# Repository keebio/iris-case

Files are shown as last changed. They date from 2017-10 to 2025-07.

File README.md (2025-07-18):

Iris Keyboard Case
==================

Here are the case design files for the [Iris](https://keeb.io/products/iris-keyboard-split-ergonomic-keyboard). It's a sandwich-style case with cutouts to accommodate the USB jack and the TRRS jack.

## Iris CE / Iris LM / Iris AE / Iris SE

Iris CE parts are in this repository: https://github.com/keebio/iris-ce-case

Iris LM parts are in this repository: https://github.com/keebio/iris-lm-case

Iris AE parts are in this repository: https://github.com/keebio/iris-ae-case

Iris SE parts are in this repository: https://github.com/keebio/iris-se-case

Case pieces
-----------

The Iris sandwich case consists of these pieces:

- Switch plate (Required)
- Bottom plate (Required)
- Middle layer (Optional)
- Top rim or Top shell (Optional)

### Case/Plate Versions

Before the release of the Iris Rev. 5 PCBs, the case parts for Rev. 3 & 4 used the same parts. However, with the release of Rev. 5-8 PCBs, the screw holes needed to be relocated to accommodate the wider USB-C port used for interconnect. Therefore, new case parts needed to be made to support the newer PCBs.

The newer case parts are called [Phoenix Edition (PE)](phoenix-edition-PE/), while the older Iris parts are now called [Legacy Edition (LE)](legacy-edition-LE).

Phoenix Edition parts and Legacy Edition parts are not compatible with each other due to the different placement of screw holes.

PE parts are compatible with Rev. 3 through 8 PCBs.

LE parts are compatible with Rev. 3 & 4 PCBs.

See additional info about Legacy Edition files in its [README](legacy-edition-LE/README.md).

Iris PE (Phoenix Edition) Parts
-------------------------------
### 3D-print STL files

For the 3D-print STL files, there are two sets of files, ones for the top shell, and ones for the middle layer. For each of these sets, there are different files based on how thick your plates are. If you have the FR4 plates or Stainless steel plates, then use the files for 1.5mm plate. If you are using 3mm acrylic plates, then use the files for the 3mm plate.

For the middle layer files for 1.5mm plates, there are two sets of files: one with a lip and one without a lip. The "lip" refers to the portion of the middle layer that extends past the standoffs and covers the sides of the 1.5mm plate, to hide the edges from view. The "No Lip" version may be more desirable for you to use if you are not using a top shell.

If you are using the top shells, you will need to use longer M2 screws, as the top shell has been designed to be threaded into directly from underneath. For 1.5mm plates, you will need [18mm screws](https://keeb.io/products/m2-screws-and-standoffs), and for 3mm plates, you will need 22mm screws.

If you choose to print the ErgoDox-style tenting legs, you will need six M3 screws (at least 16mm) and six M3 nuts. The legs and washers are best printed at 0.16mm quality or better.

Additional notes
----------------

Some of the files only have a left half, just mirror the file to produce a right half if needed.

Design info
-----------

A lot of these files have been derived from the following file: [iris-plate-design.ai](references/iris-plate-design.ai). By toggling various layers in that file, you can see various info on switch cutouts, screw holes, inner/outer edges, etc.

Screws and Standoffs
--------------------

This case was designed to use M2 screws and standoffs. The holes in the middle layers are for the standoffs, while the holes in the top and bottom layers are only wide enough for the screws. M2 screws and standoffs that fit the case can be purchased at Keebio: [M2 Screws & Standoffs](https://keeb.io/products/m2-screws-and-standoffs)

Fabrication of Acrylic Parts
----------------------------

### Places to go

- [Sculpteo](https://www.sculpteo.com)
- [Ponoko](https://www.ponoko.com)

### Middle Layer Thickness
If you're having the middle layers made, from the top of the switch plate to the top of the bottom plate, the minimum distance between the two required is 12mm if the plastic on the header pins is removed. The requirement is slightly more (about 13.5mm) if you leave the plastic on. Therefore, the following middle layer thicknesses are needed based on the thickness of the switch layer:

- 1.5mm Stainless steel switch plate: 10.5mm
    - Usually accomplished with:
        - 2x4.5mm + 1x1.5mm layers
        - or 3x3mm + 1x1.5mm layers
        - or 4x3mm layers
- 3mm acrylic switch plate: 9mm
    - Usually accomplished with:
        - 2x4.5mm layers
        - or 3x3mm layers

STL Files for 3D printing
-------------------------
A couple of STL files have also been included for the middle layers and are both single pieces. They are designed for the left half, so to get the right half, you will need to flip them within your slicer software.

One version allows the Ergodox EZ legs to be used with it. In addition to the legs, you'll need M3 nuts to allow the leg screws to screw into.

Community-Made Files
--------------------
Files not designed by Keebio are placed into the [community-made](community-made/) folder and also include links to other designs not hosted in this repository.

License
-------
These case files are released under the MIT License.

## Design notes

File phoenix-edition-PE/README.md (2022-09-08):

# Iris PE Case Notes

## 1u Adapter for 3mm Plates

For the 3mm acrylic plates, due to the enlarged cutouts at the thumb area for the stabilizer, using two 1u keys there can be a bit loose sometimes. To remedy this, one thing you can do is 3D-print an [adapter for the thumb area](Iris%20PE%201u%20Adapter%20for%203mm%20Plates.stl). This adapter will also the two switches to clip in and stay in place better.

Once printed, insert the adapter from the underside of the plate, as shown here:

Bottom view:
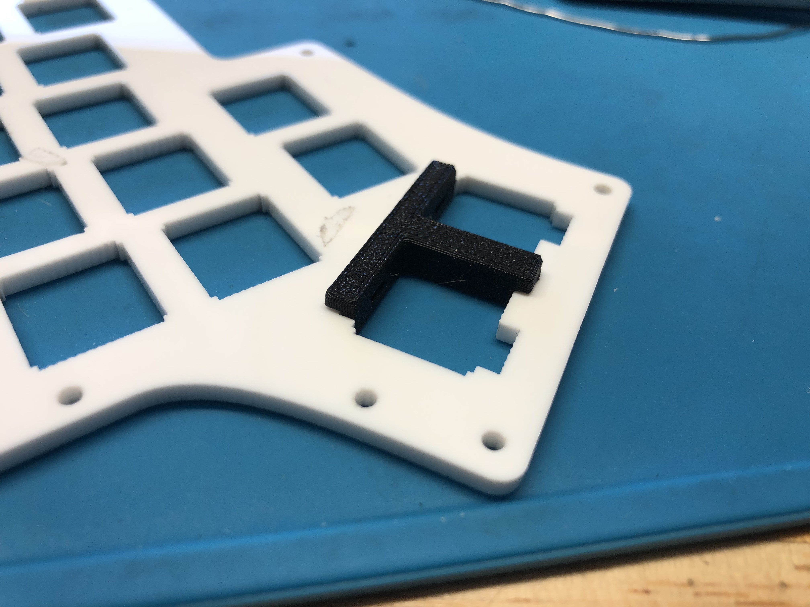
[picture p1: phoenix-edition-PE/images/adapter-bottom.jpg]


Top view:
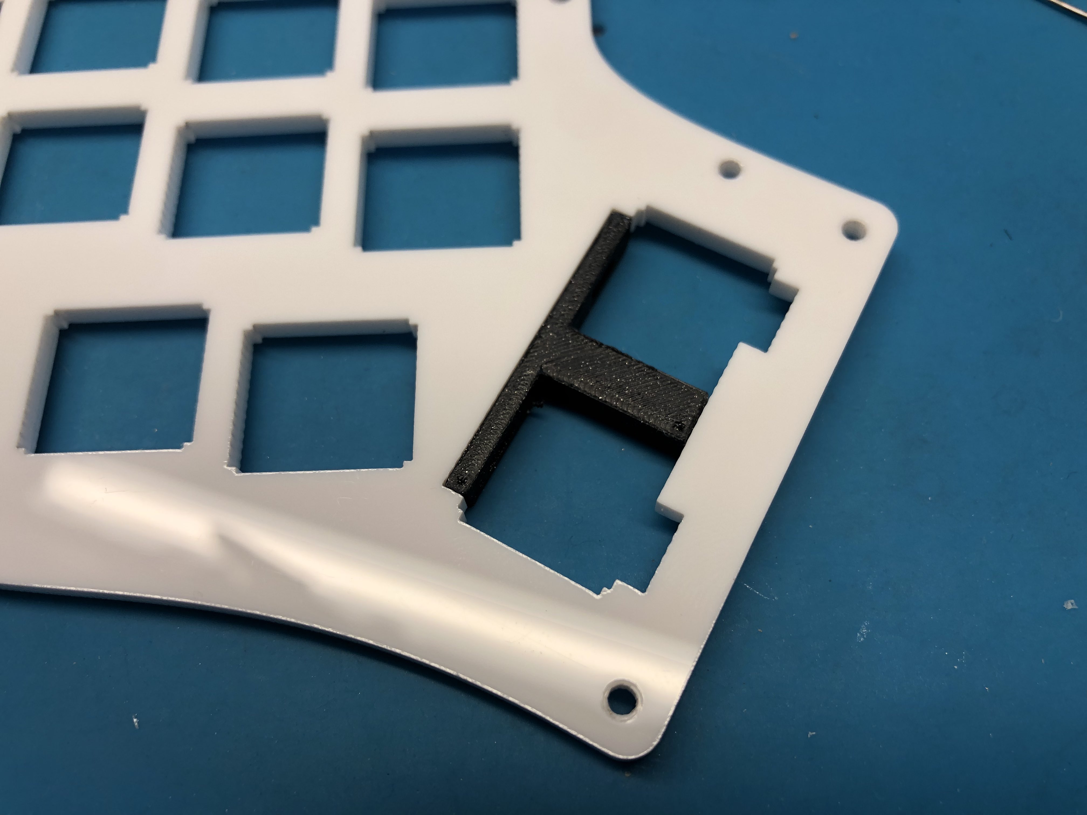
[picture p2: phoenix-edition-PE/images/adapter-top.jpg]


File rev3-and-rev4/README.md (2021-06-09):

Iris Rev. 3 & 4 Files
=====================

Iris Rev. 3 and 4 PCBs have the same exact USB-C and TRRS port positioning, so they also use the same case design.

Most of the files are designed for the the left half, so to get the right half, just mirror the file

Top Shell Files
---------------

For the top shell files in this folder, the screws are threaded in from underneath, instead of from the top for the files in the top level folder. The main benefit of this style is that the screws are not visible from the top.

The depth of the screw hole is about 5mm, so the length of the M2 screw you need with depend on the thickness of the plates and mid layer you use. Make sure the screw threads into the top shell for at least 3mm. For example, if you are using 1.5mm switch/bottom plates and 12mm middle layer, then you would need to use 18mm screws at the minimum (3 + 1.5 + 12 + 1.5 = 18).

Middle Layer Files
------------------

Since some of the middle layer files have port cutouts, the version that needs to be used is dependent on the the switch plate thickness. For FR4 plates, use the files designated for 1.5mm plates. For 3mm acrylic plates, use the files for 3mm plates.

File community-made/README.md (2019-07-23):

Community Made Files
====================

This folder contains files generated by other people in the community. If you have any questions about these files, please contact the creator of those files.

Projects on Thingiverse
-----------------------

- [Iris Keyboard Case (v2) vy holtenc](https://www.thingiverse.com/thing:3186129)
- [Keebio Iris v2.5+ middle layer with 3D-printed tenting legs by MichaelTV](https://www.thingiverse.com/thing:3392322)
- [Iris keyboard case by botstyle](https://www.thingiverse.com/thing:3545130)

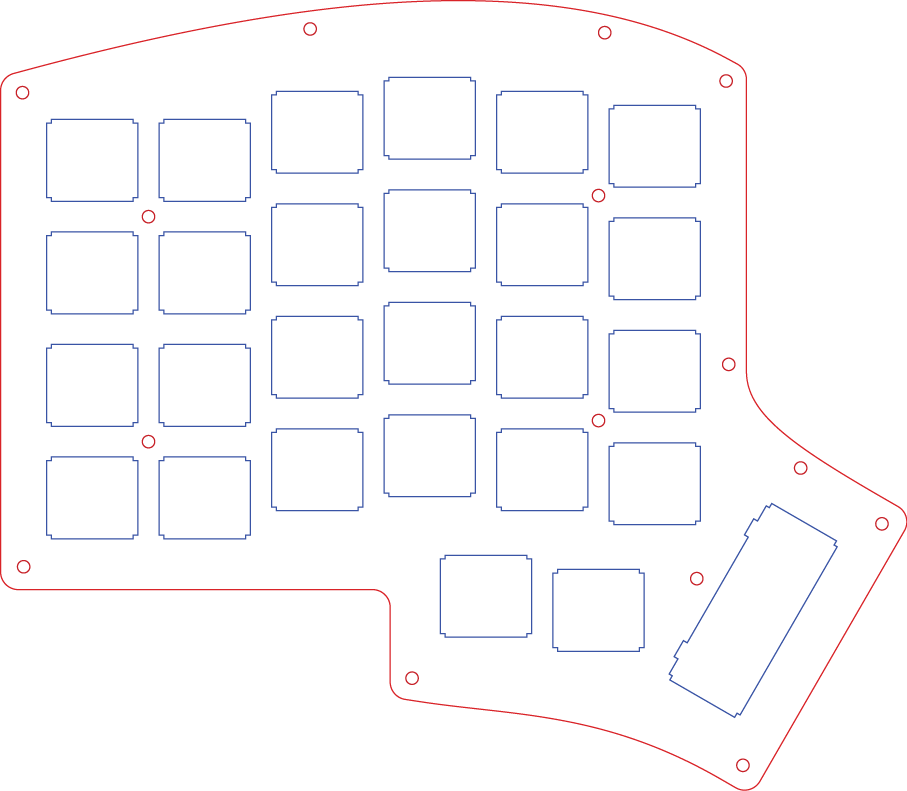
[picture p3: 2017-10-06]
images/iris-switch-plate.png

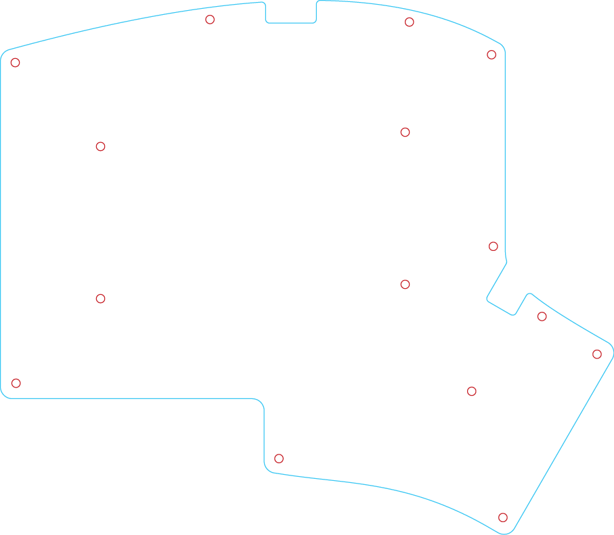
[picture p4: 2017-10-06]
images/iris-bottom-plate.png

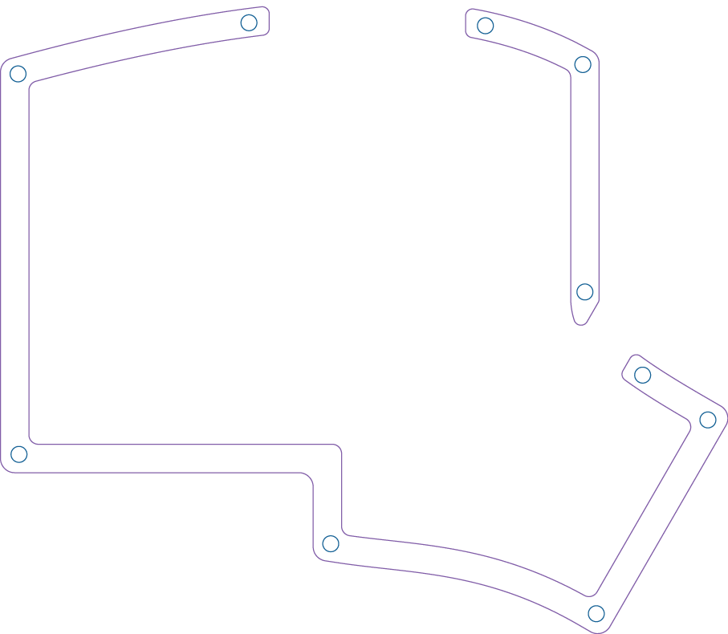
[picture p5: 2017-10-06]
images/iris-middle-layer.png

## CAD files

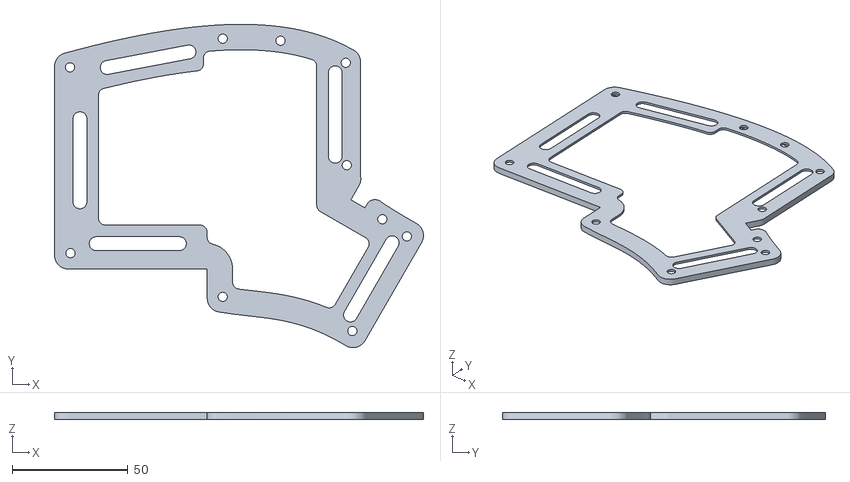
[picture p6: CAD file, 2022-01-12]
Iris Bottom Plate SKUF Alignment Guide.stl
159.4 x 139.7 x 3.00

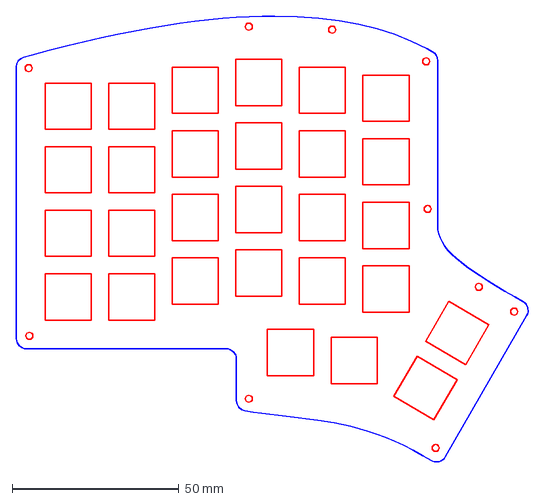
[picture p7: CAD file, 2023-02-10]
phoenix-edition-PE/iris-PE-switch-plate-mx-1u-only.dxf
153.9 x 133.7 mm

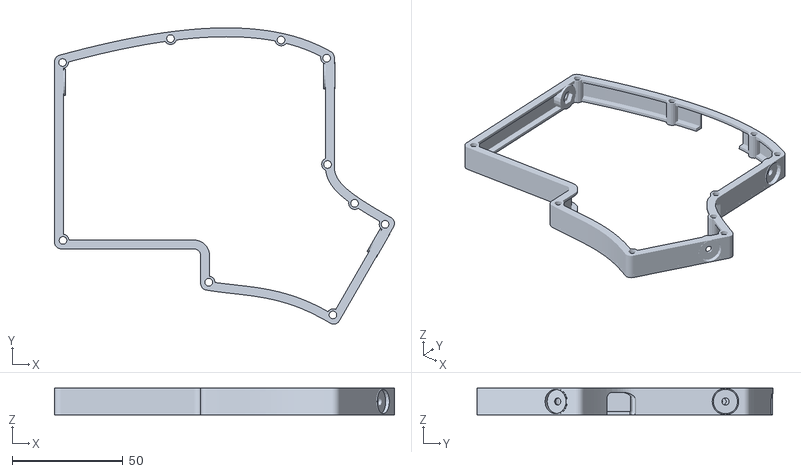
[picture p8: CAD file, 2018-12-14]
rev2-only/Iris R2 Thin Shell Tenting.stl
153.4 x 133.7 x 12.0

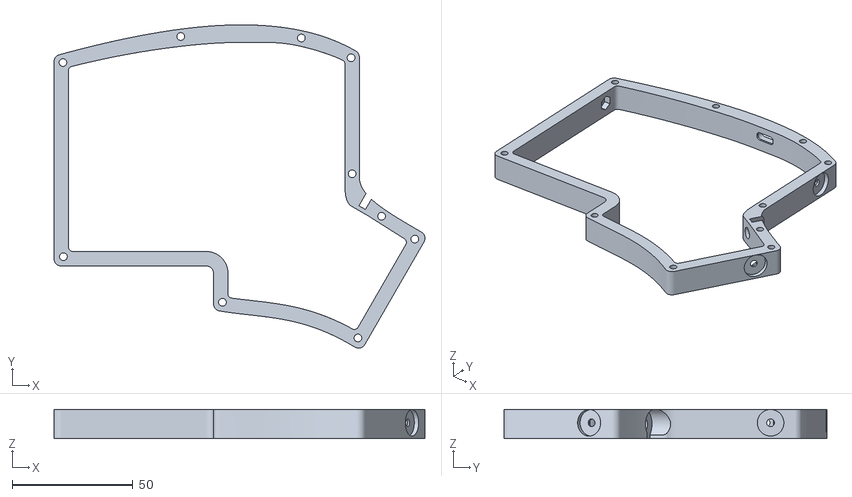
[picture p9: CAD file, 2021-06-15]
rev3-and-rev4/Iris R4 Middle Layer - Ergodox Tent Kit for 3mm Plate.stl
153.4 x 133.7 x 12.0

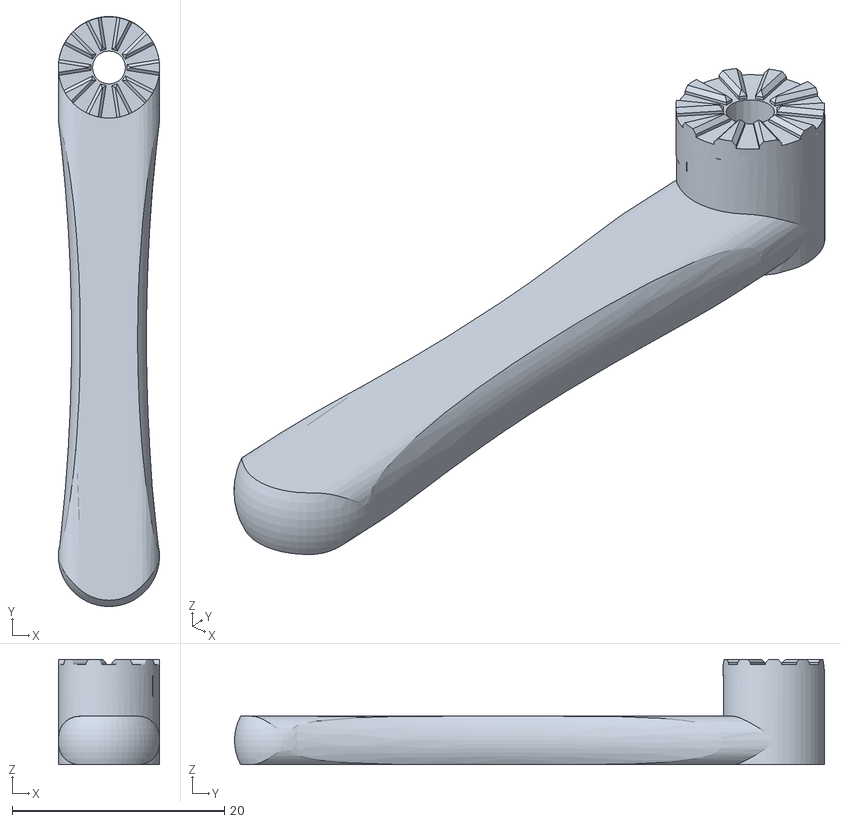
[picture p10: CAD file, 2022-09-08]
tenting-kit/ErgoDox-style Toothed Tenting Leg.stl
9.53 x 55.6 x 9.90

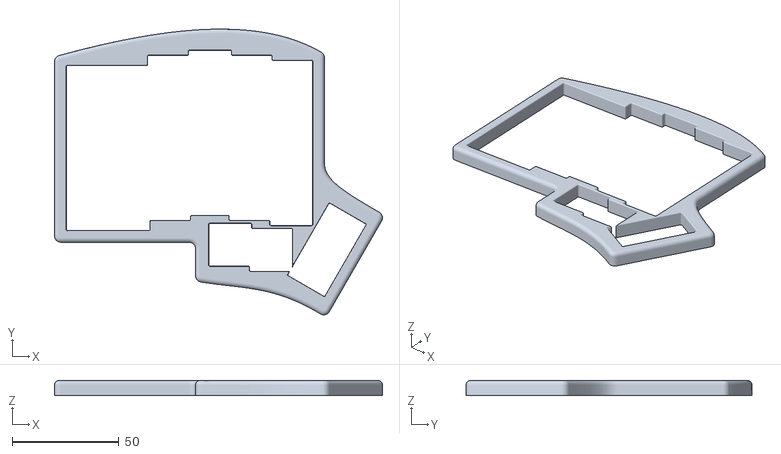
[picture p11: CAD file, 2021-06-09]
rev3-and-rev4/Iris Top Shell Rev. 4.stl
153.4 x 133.7 x 7.00

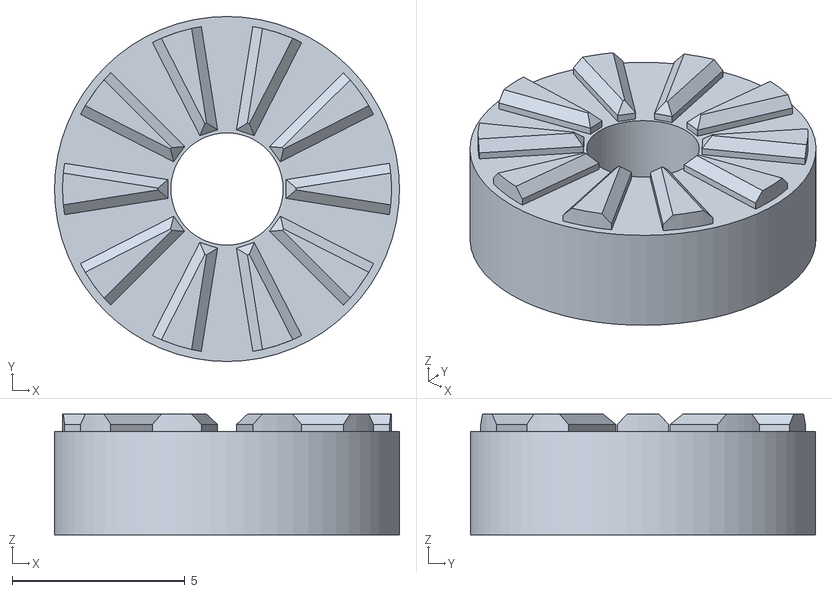
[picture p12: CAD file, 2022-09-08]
tenting-kit/ErgoDox-style Toothed Tenting Leg Adapter.stl
10.0 x 10.00 x 3.50

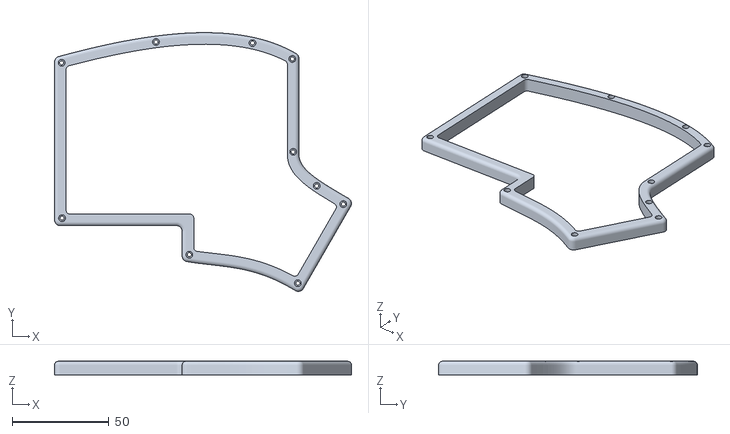
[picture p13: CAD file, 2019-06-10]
Iris Hi-Pro Top - Thin Rim.stl
153.5 x 133.7 x 7.00

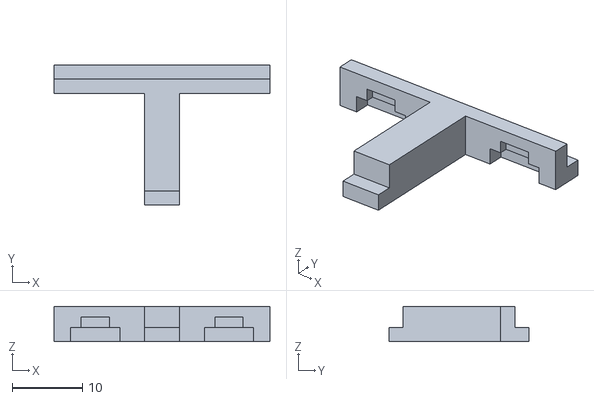
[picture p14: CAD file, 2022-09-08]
phoenix-edition-PE/Iris PE 1u Adapter for 3mm Plates.stl
30.8 x 20.0 x 5.00

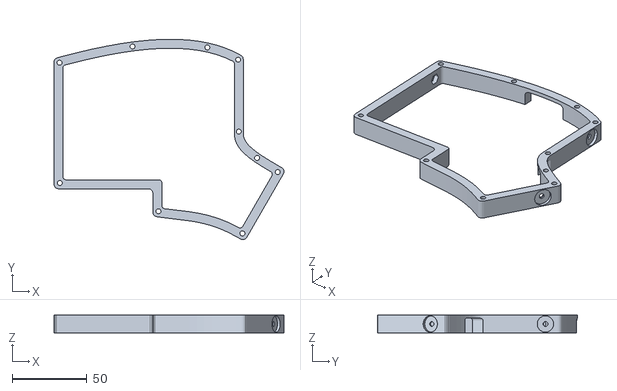
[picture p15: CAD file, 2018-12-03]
rev2-only/Iris R2 Middle Layer - Ergodox Tent Kit.stl
153.4 x 133.7 x 12.0

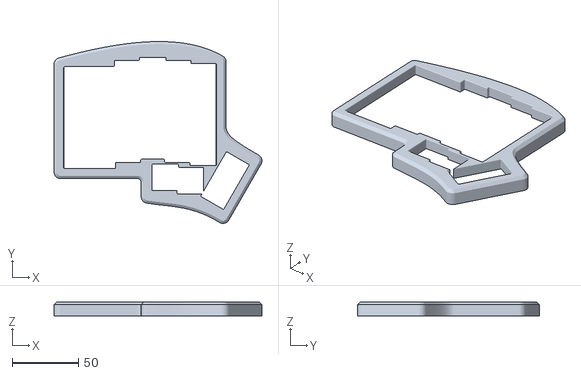
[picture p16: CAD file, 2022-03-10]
phoenix-edition-PE/Iris PE Top Shell for 3mm plate.stl
157.4 x 137.7 x 10.7

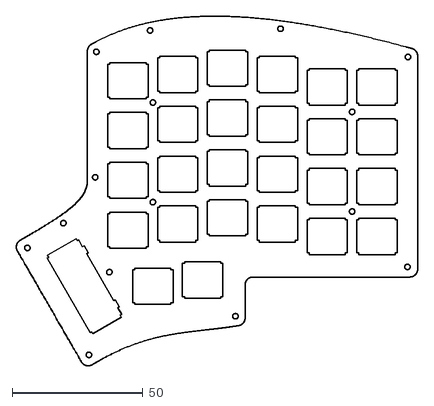
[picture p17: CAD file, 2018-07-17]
top_left.dxf
153.5 x 133.7

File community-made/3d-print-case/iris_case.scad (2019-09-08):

////////////////////////////
// User configurable options
////////////////////////////

two_unit_thumb = false;
stabilizers = true;
usb_c_pro_micro = true;
trrs_diameter = 6.55;
selector = 1;

///////////////////////////////
// Source code below this point
///////////////////////////////

$fs = .3;
$fa = 6;

mx_switch_height = 5;
pcb_height = 1.6;
trrs_jack_size = 5;
plate_thickness = 1.5;
height = mx_switch_height + pcb_height + trrs_jack_size + plate_thickness;
wall_thickness = 1.8;

_1_4th = 1/4 * 25.4;
key_distance = 3*_1_4th;
thumb_angle = -29.36;
thumb_offset = 5 * key_distance + 26.19;

_3_32nds = 3/32 * 25.4;
col3and5Shift = 2*_3_32nds;
col4Shift = 3*_3_32nds;
col6Shift = _3_32nds;

screw_head_diameter = 6.75;

mini_usb_port_width = 7.5;
usb_c_port_width = 9;

usb_port_height = usb_c_pro_micro == true ? 3.2 : 2.5;
left_usb_z_position = height - mx_switch_height - pcb_height - usb_port_height/2;
right_usb_z_position = plate_thickness + usb_port_height/2;

trrs_right_offset = 11.14 + trrs_jack_size/2;
trrs_left_offset = 13.32 + trrs_jack_size/2;

left = 1;
right = 2;

TOP_LEFT = 1;
BOTTOM_LEFT = 2;
TOP_RIGHT = 3;
BOTTOM_RIGHT = 4;
LEFT = 5;
RIGHT = 6;

module drawCase() {
    if(selector == TOP_LEFT || selector == LEFT) top(left);
    if(selector == BOTTOM_LEFT || selector == LEFT) bottom(left);
    if(selector == TOP_RIGHT || selector == RIGHT) top(right);
    if(selector == BOTTOM_RIGHT || selector == RIGHT) bottom(right);
}

module pcb_fit_test() {
    pro_micro_width = 17.5;
    case_skirt(wall_thickness, 0, wall_thickness/2);
    translate([47.5, 69, 0]){
        linear_extrude(pcb_height) {
            rotate(90) {
                import (file = "iris-pcb.dxf");
            }
        }
    }
    translate([-col4Shift - _3_32nds - 2.2, -pro_micro_width/2 + 3.5 * key_distance, pcb_height]) {
        cube([10, pro_micro_width, pcb_height]);
    }
    translate([-col4Shift - _3_32nds - 3.2, -mini_usb_port_width/2 + 3.5 * key_distance, pcb_height]) {
        cube([10, mini_usb_port_width, usb_port_height]);
    }
}

module usb_cutout(selector) {
    cutout_adjust = 0.1;
    width_top = mini_usb_port_width + cutout_adjust;
    width_bottom = 4.85 + cutout_adjust;
    port_height = usb_port_height + cutout_adjust;
    angle = selector == left ? 90 : 270;
    promicro_extension = 2;
    z_position = selector == left ? left_usb_z_position : right_usb_z_position;
  
    translate([-col4Shift - _3_32nds - promicro_extension, 3.5 * key_distance, z_position]) {
        rotate([0, angle, 0]) {
            hull () {
                if (usb_c_pro_micro) {
                    radius = 1;
                    usb_cutout_cylinders(-port_height/2 + radius, usb_c_port_width + cutout_adjust, radius);
                    usb_cutout_cylinders(port_height/2 - radius, usb_c_port_width + cutout_adjust, radius);
                } else {
                    radius = 0.5;
                    usb_cutout_cylinders(-port_height/2 + radius, width_top, radius);
                    usb_cutout_cylinders(0, width_top, radius);
                    usb_cutout_cylinders(port_height/2 - radius, width_bottom, radius);
                }
            }
        }
    }
}

module usb_cutout_cylinders(x, y, radius) {
    translate([x, y/2 - radius]) {
        cylinder(r=radius, h=10, center=true);
    }
    translate([x, -y/2 + radius]) {
        cylinder(r=radius, h=10, center=true);
    }
}

module usb_spacer(selector) {
    spacer_height = 5;
    spacer_margin = 5;
    spacer_width = usb_c_pro_micro == 1 ? usb_c_port_width + spacer_margin : mini_usb_port_width + spacer_margin;
    z_position = selector == left ? -spacer_height + left_usb_z_position : right_usb_z_position;

    translate([-key_distance, 3.5 * key_distance - spacer_width/2, z_position]) {
        cube([key_distance, spacer_width, spacer_height]);
    }
}

module reset_hole() {
    reset_hole_diameter = 2;
    reset_offset_pcb = 2.5;
    reset_offset_usb = 16;
    translate([0, 3.5 * key_distance + reset_offset_usb, height - mx_switch_height - pcb_height - reset_offset_pcb]) {
        rotate([0, 270]) {
            cylinder(d = reset_hole_diameter, h = 15);
        }
    }
}

module top(selector) {
    mirror([0, selector == right ? 1 : 0, 0]) {
        rotate ([180, 0, 0]) {
            translate([0, -145, -height]) {
                difference() {
                    union() {
                        difference() {
                            case_base(wall_thickness);
                            difference() {
                                union () {
                                    translate([-150, -150, -height + trrs_jack_size/2 + plate_thickness]) {
                                        cube([300, 300, height]);
                                    }
                                    translate([0, 0, trrs_jack_size/2 + plate_thickness -0.001]) {         
                                        case_skirt(wall_thickness/2, -0.001, wall_thickness/2 + 0.1);
                                    }
                                }
                                if (selector == right) {
                                    usb_spacer(right);
                                }
                            }
                            translate([0, 0, -plate_thickness]) {
                                case_base();
                            }
                            // Cut interior corner to fit PCB
                            translate([4 * key_distance - 1, 3.5 * key_distance, 0]){
                                rotate(-45) {
                                    cube([4, 4, 2 * (height - mx_switch_height)], center = true);
                                }
                            }
                        }                      
                        top_screw_posts();
                    }
                    reset_hole();
                    key_cutouts();
                    if (selector == left) {
                        trrs_cutout(-trrs_left_offset);
                        trrs_indent(-trrs_left_offset);
                        usb_cutout(left);
                        usb_spacer(left);
                    } else if (selector == right) {
                        trrs_cutout(-trrs_right_offset);
                        usb_cutout(right);
                    }    
                }
            }
        }
    }
}

module bottom(selector) {
    mirror([0, selector == right ? 1 : 0, 0]) {
        translate([110, 50, 0]) {
            difference() {
                union() {
                    difference() {
                        case_base(wall_thickness);
                        difference() {
                            union () {
                                translate([-150, -150, trrs_jack_size/2 + plate_thickness + wall_thickness/2]) {
                                    cube([300, 300, height]);
                                }
                                translate([0, 0, trrs_jack_size/2 + plate_thickness + 0.001]) {     
                                    case_skirt(wall_thickness + 0.001, wall_thickness/2 -0.05, wall_thickness/2);
                                }
                            }
                            if (selector == left) { 
                                usb_spacer(left);
                            }
                        }
                        translate([0, 0, plate_thickness]) {
                            case_base();
                        }
                    }
                    screw_posts(plate_thickness + trrs_jack_size - 0.15, screw_head_diameter + 2, screw_head_diameter + 2);
                }
                hull () {
                    reset_hole();
                    translate([0, 0, 10]) {
                        reset_hole();
                    }
                }
                bottom_screw_holes();
                trrs_position = selector == left ? -trrs_left_offset : -trrs_right_offset;
                hull () {
                    trrs_cutout(trrs_position);
                    translate([0, 0, 10]) {
                        trrs_cutout(trrs_position);
                    }
                }        
                if (selector == left) { 
                    trrs_indent(-trrs_left_offset);
                    usb_cutout(left);
                } else if (selector == right) {             
                    usb_spacer(right);
                    usb_cutout(right);
                }
                // Add a small indent in bottom place for the TRRS jack
                trrs_space_width = 6.5;
                translate([0, 0, -trrs_jack_size/2 + 2.00]){
                    position_trrs(trrs_position - trrs_space_width/2, -19.8){
                        cube([plate_thickness + 1, trrs_space_width, 13]);
                    }  
                }
            }
        }
    }
}
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

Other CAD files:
iris-switch-plate-3mm-thick.dxf
phoenix-edition-PE/iris-PE-switch-plate-mx-3mm.dxf
rev2-only/Iris R2 Thin Shell.stl
rev3-and-rev4/Iris Top Shell Rev. 4 - With Encoder.stl
rev2-only/Iris R2 Middle Layer - Single Piece.stl
rev3-and-rev4/Iris R4 Middle Layer - Ergodox Tent Kit for 1.5mm Plate.stl
interior-plates/Iris Middle Layer for Interior Screw Plates.stl
iris-switch-plate_left.dxf
legacy-edition-LE/Iris LE Middle Layer - Ergodox Tent Kit for 1.5mm Plate.stl
legacy-edition-LE/Iris LE Middle Layer - Normal for 1.5mm Plate.stl
legacy-edition-LE/iris-rev3-bottom-plate.dxf
legacy-edition-LE/iris-switch-plate-3mm-thick.dxf
legacy-edition-LE/iris-switch-plate_left.dxf
legacy-edition-LE/non-plate-enclosed/Iris R3 Middle Layer - 2 Piece.stl
legacy-edition-LE/non-plate-enclosed/Iris R3 Middle Layer - Ergodox Tent Kit for 1.5mm Plate.stl
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

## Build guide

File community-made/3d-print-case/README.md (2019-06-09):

3D Print Iris Keyboard Case 
===========================

This is the source code for a 3D printable case for the [Iris keyboard](https://keeb.io/products/iris-keyboard-split-ergonomic-keyboard).
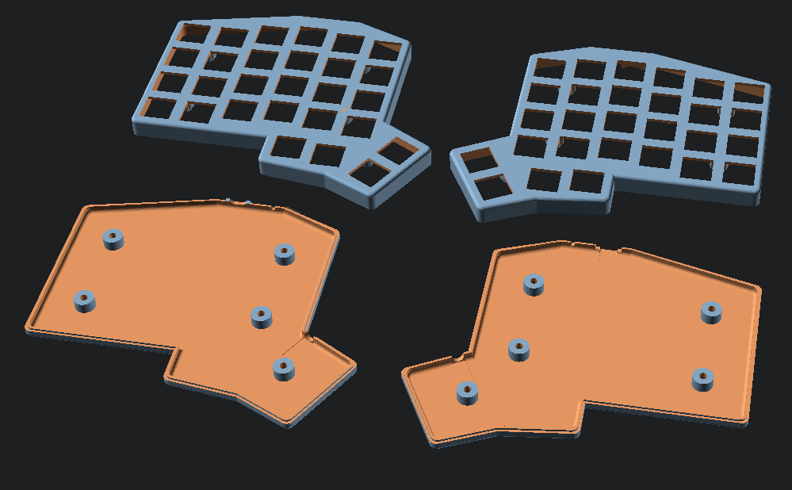
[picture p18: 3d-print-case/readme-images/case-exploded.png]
Iris case (exploded)


The 3D print case supports many different combinations of options, and including generated files for all of them would bloat the size of this repository. Because of this, the source file and instructions for generating the STLs are provided in this document.

What's supported
----------------
This case does not support all configuration options for the Iris. If you would like to add any of the missing features, the source code for the case is available in this repo. Please contribute your changes back once they are tested.

### Supported
- Iris 2.7 and earlier PCB
- MX compatible switches
- 1u thumb keys 
- 2u thumb keys
- PCB mount stabilizers (both clip and screw-in)
- TRRS cables < 10mm in diameter (6.5mm recommended)
- Micro USB pro-micro
- Elite-C controller

### Unsupported
- Iris 3.0 PCB
- Alps switches
- Low profile switches
- DIP sockets
- Plate-mount stabilizers
- Threaded screw inserts

How to generate STL files from this project
-------------------------------------------
1. Install [OpenSCAD](http://www.openscad.org/)
2. Download `iris_case.scad` from this repository and open it using OpenSCAD
3. Configure the options you want in iris_case.scad
    - Please see the **User configurable options** section for details
4. For each of the four case parts:
    1. Update `selector` to the correct value for that case part
    2. Click the render button in the top bar (cube with an hour glass icon)
    3. Wait for the case to render (this may take a few minutes)
    4. Click the export button (labeled STL) in the top bar to export the STL

### User configurable options
- **two_unit_thumb**
    - If `false`, two 1u switch cutouts are generated on the diagonal thumb section
    - If `true`, a single centered cutout for a 2u thumb key is generated
- **stabilizers**
    - `stabilizers` only has an effect when using a 2u thumb key
    - If `false`, PCB stabilizer cutouts are not generated
    - If `true`, stabilizer cutous are generated for the 2u thumb key
- **usb_c_pro_micro**
    - If `false`, USB cutout is shaped for micro-USB
    - If `true`, USB cutout is shaped for USB-C
- **trrs_diameter**
    - The way the Iris PCB is designed, the left-side TRRS cable is extremely 
close to the edge of the PCB. Since the case must be wider than the PCB, 
this can cause the case to interfere with TRRS cables that have a diameter 
larger than 6.55 millimeters. 
    - Increasing `trrs_diameter` will add a divot into the side of the case 
to accomodate larger cables. This can make the wall section near the cable too thin and compromise 
the print quality (although it will be covered up by the larger cable). A 
smaller sized cable is the recommended solution.
- **selector**
    - `selector` controls which part of the case is generated. To generate the full case, each part must be selected separately, rendered, then exported.
    - If `1`, top left
    - If `2`, bottom left
    - If `3`, top right
    - If `4`, bottom right
    - If `5`, Top and bottom left hand
    - If `6`, Top and bottom right hand

Case assembly
-------------
The [Iris build guide](https://docs.keeb.io/iris-build-guide/) still applies to the assembly process, with a few additional callouts:
- This case was designed to use M3 screws that are 8mm long. The screw shaft will pass freely through the holes in the bottom layer, and will bind into the plastic of the top layer. 
    - Using screws longer than 8mm (threads longer than 6mm) may deform the top layer if they are fully screwed in.
- After soldering the switches, the pro-micro must be positioned so that the USB connector is within the cutout of the top layer, and must be leveled so that the USB connector is not at an angle.
    - Inserting a small amount of material (like paper) under the end opposite the USB until the first solder points are done can help level the connector until it's fixed in place by solder.
- If you're using stabilizers, be sure to install them before soldering the switches. Because the 3D print case fully encloses the top half of the PCB, it's not possible possible to install them later without desoldering.
    - Screw-in stabilizers are recommended because the snap-in variety can sometimes come unseated when removing keycaps, which is hard to fix for the same reason.

Fabrication
-----------

### FDM Printing
This case is designed for printing on consumer grade FDM printers. These printers are the most common variety owned by hobbyists, schools, libraries, and maker spaces.

Many printing materials will work, but the case has been designed and tested using PLA.

### Shapeways
[Shapeways](https://www.shapeways.com) is a 3D printing company that will produce your model and mail it to you. Their services are significantly more expensive than producing the case yourself, but they are an option if you don't have access to a 3D printer, or if you want an especially high quality print.

Shapeways' "Strong and Flexible" plastic is recommended for printing this case.

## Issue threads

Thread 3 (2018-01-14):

How long are all the paths in your design combined?

danielo515, 2018-01-14:
Hello,

I wanted to order this case from lasergist because it is sold out on keeb.io. Thanks to the README I can fulfill the creation form without problems except for one field, the PATH LENGTH:

>PATH LENGTH
>How long are all the paths in your design combined?

If you can tell me what is the correct value for that parameter I'll ve very grateful

MungFuSensei, 2018-01-15:
Would love an answer for this as well.

nooges, 2018-01-15:
For the switch plate, path length is 2224.7mm. For the bottom plate, it's 626.4mm.

However, I probably wouldn't order from Lasergist, as they seem to have problems filling orders or communicating these days: https://www.reddit.com/r/MechanicalKeyboards/comments/73ub8z/r_lasergist_no_longer_active_but_website_still/

danielo515, 2018-01-16:
Thank you very much @nooges !!
That information should be added to the readme in my opinion.

I made an order to lasergist this summer (one or maybe two months ago) and I had no problem at all. Maybe that is a matter of the past ?

thorinmesser, 2018-12-18:
+1 for putting this in the readme.

Closed 2018-01-15.

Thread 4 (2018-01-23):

No interior screw plans

t-taylor, 2018-01-23:
Would it be possible to get the [interior screw designs](https://keeb.io/products/iris-keyboard-case-plates?variant=5602193539102)?

nooges, 2018-02-22:
Added in a1e3ba0e27ff82d7aa4968b7df33b224162ece72

Closed 2018-02-22.

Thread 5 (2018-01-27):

Ponoko stroke width?

gwerbin, 2018-01-27:
Ponoko's laser cuts a 0.01mm stroke. Do the design files need to be adjusted for that? It seems awfully tiny -- it's barely visible in Inkscape unless I zoom in to almost 200%.

The generated SVGs are [here](https://github.com/gwerbin/iris-case/tree/4e00ae68ce2a17e364ff3a293b6c9c4233285e92/vector).

geoah, 2018-02-19:
@gwerbin did you try to get these cut with ponoko? Wondering how they came out.

gwerbin, 2018-02-19:
I didn't get these plates cut but I did get a custom design (via Swillkb) done by Ponoko. I didn't set a kerf in Swillkb, and the switches fit pretty well.

I'm not sure if that helps at all. Maybe I can compare the switch openings in the Iris file to the ones in my file and adjust accordingly.

But now that you've teased the Rorschach maybe I'll put this whole idea on hold ;)

nooges, 2018-02-22:
Yeah, when generating files for Ponoko, you need to set the color of the lines to blue and set stroke width to 0.01mm. It's not really the cutting width of their laser, it's just the format that they'd like the files to be in.

Closed 2018-02-22.

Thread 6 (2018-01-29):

Confirm dimensions for sculpteo

Jennetters, 2018-01-29:
Hi There, I was uploading the middle layer to sculpteo, however when I try to add the dimensions specified, their software forces me to a fixed aspect ratio of 155.3mm x 133.9mm or 153.7mm x 132.5mm.

Could you please confirm that the dimensions need to be 153.7mm x 133.9mm. If so, do you have suggestions for how to get around the fixed aspect? Thanks.

nooges, 2018-01-29:
For the middle layer, the height is shorter, due to the USB cutouts at the top. I used the dimensions of 153.7mm x 132.5mm.

Closed 2018-01-29.

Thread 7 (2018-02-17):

Update README for tented case

kevinduffey, 2018-02-17:
The current README indicates the middle, bottom and switch layers  for a case.  Yet, there is a tented version, which when I enter in the Sculpteo  site, indicates  slightly  different dimensions than what the info  says. I assume  its right  since I can not adjust the  2nd dimension as  it auto-adjusts when I enter the 153.7 dimension data  in.

It is not clear if the top layer is ALSO needed, or it that is only for the TENTED version middle layer.

nooges, 2019-07-23:
Done

Closed 2019-07-23.

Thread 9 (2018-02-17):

Middle layer tent has  different dimensions in Sculpteo

kevinduffey, 2018-02-17:
The middle layer tented file indicates a  slightly  small dimension which can not  be   adjusted  on the Sculpteo site. Are the dimensions correct?

153.7 × 121.8 mm

geoah, 2018-02-20:
I'm currently dealing with the same issue :D

I can only assume that the scale just needs to be the same with the rest, which is `26.5%`.
With this scale the height comes down to `132.5mm` which is the same as the suggested for the non-tent middle layer.

So I assume that tent middle layer is `167.2mm x 132.5mm`.

nooges, 2018-02-22:
Added the dimensions to the README in bd8124c742f3b9c94d986b8c2a66fabdf8fd7629

Closed 2018-02-22.

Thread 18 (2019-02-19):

Middle layer STL file chirality.

keunhong, 2019-02-19:
I am trying to print the ergodox tentable middle layers and it looks like the STL files are meant to be mirrored before printing to get both sides--is this correct?

Thanks.

keunhong, 2019-03-11:
To answer my own question, it seems like the middle layer for the is reversible. I've printed two of the same and they both fit fine, although it means the two sides aren't symmetrical.

I've attached a mirrored copy of the model though, in case anyone wants it.

[iris middle layer ergotox tent kit left right.zip](https://github.com/keebio/iris-case/files/2951806/iris.middle.layer.ergotox.tent.kit.left.right.zip)

Closed 2019-03-11.

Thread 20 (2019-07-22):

REQUEST: higher poly stl files

jocelynmallon, 2019-07-22:
Hi, it would be nice to have higher poly count stl files for smoother printing in materials other than PLA; e.g. resin prints could be perfectly smooth.

nooges, 2019-07-23:
Yeah, I'll need to do a redesign in a different CAD program sometime, because the one I did the STL files in doesn't have an option to export higher quality output.

si14, 2020-04-02:
@nooges would you be interested in Fusion360 files for rev4? Aside from poly count which is very visible on PLA printed curves, I've also noticed a few other problems in current 3d printed mids:

* they can be substantially lower for rev4 if used with inserts instead of standouts
* usb-c port interferes with the mid layer and makes it slightly off centre
* tolerances on holes for nuts to hold tenting legs can be tighter to hold nuts in place
* round openings ideally should be teardrop shaped, otherwise their tops are flat, not round

I can try and fix all that, but knowing it'll be helpful for someone else would make it more worthwhile

nooges, 2020-04-02:
@si14 Yeah, I would be interested, as I don't have time to redo it all myself.

si14, 2020-04-02:
@nooges I'll try to come up with something this weekend and let you know how it works out. Do you have any constraints or preferences on hardware? How dead set are you on using the standoffs? Any tips or advice if you don't mind me asking?

si14, 2020-04-14:
@nooges sorry for a delay. I think I got it more or less right https://a360.co/2Xz4Tp7 (can you download it from there?)

Here are a few changes:

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

Current STL doesn't quite fit and bulges out, new one doesn't. I think USB-C port is a touch too close in the current one

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

USB-C cutout is a bit more square so it prints better. Also no holes on the sides

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

TRRS cutout is aligned with the bottom plate and the hole for the socket is now teardrop shaped so it doesn't interfere with the socket

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

It's really hard to show on the photos, but higher poly STLs are visibly smoother on the curves

I've also made standouts fit tighter so it's easier to screw the plates. They were very loose with the current STL, making it difficult to screw everything in one go.

I've done my best to keep it as parametric as I could, so minor adjustments shouldn't be a problem. The only hacky part is finding centres for those holes using constraints, as they exported as curves and Fusion can't tell they are circles with a centre point. Please let me know if I can help in any way.

Here it is as an STL just in case:
[mid_layer.stl.zip](https://github.com/keebio/iris-case/files/4476188/mid_layer.stl.zip)

I also think that if you will ever want to mass-produce them for sale it can be optimised quite a bit. I'd reduce thickness where it's not needed and cut them in two so that multiple mid layers can fit on a bed.

I think for my own keyboard I'll probably ditch the bottom plate altogether and design a bottom with embedded nuts so it's slimmer and to avoid bottom screw heads scratching my table. I can share a design if you're interested.

Oh yes, and it'd be great if you could provide a dxf version for `iris-plate-design-rev2-and-rev3.ai` going further. I had to install a trial version of Illustrator just to convert it to something Fusion will import, and Inkscape doesn't handle layer names.

austenc, 2020-10-13:
Hey @si14

These look awesome! I'd like to make one that supports ergodox legs for tenting. Unfortunately I can't seem to download the file from the link you posted. Any chance you could attach a zip of those here, or email them to me?

Thank you!

si14, 2020-10-14:
Hey @austenc ! Thanks for your kind words. Here it is:
[mid layer v9.f3d.zip](https://github.com/keebio/iris-case/files/5379990/mid.layer.v9.f3d.zip)

Please let me know if it works alright for you (and I hope you won't be too offended by my modelling…)

austenc, 2020-10-15:
Thank you very much @si14 -- the modeling is great by the way! Saves me a bunch of trial and error trying to get the fit right myself. I printed one from the STL files above and it fits very well, thank you!

I haven't added the ergodox stuff yet, but I did export a left and right side from your fusion file in this zip archive. Perhaps others who find this thread will find it helpful.
[iris-rev4-midlayers.zip](https://github.com/keebio/iris-case/files/5381515/iris-rev4-midlayers.zip)

nooges, 2020-10-27:
@si14 @austenc I've added the new mid layer files in this commit: af8f4875c47165192e01a78bc5c48c85ca2b0284

I'll keep this issue opened, as I still need need to get around to adding the Ergodox leg version of the updated design.

austenc, 2020-10-28:
Awesome @nooges, and thanks for the epic keebs 🤗

nooges, 2020-10-28:
@austenc Added Ergodox leg version in today: https://github.com/keebio/iris-case/blob/master/rev3-and-rev4/Iris%20R4%20Middle%20Layer%20-%20Ergodox%20Tent%20Kit%20for%201.5mm%20Plate.stl

Closed 2020-10-28.

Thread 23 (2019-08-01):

Creating middle layer stl file for the opposite hand

take, 2019-08-01:
Hi thanks for the awesome keyboard :) I'm totally in love with it.

I have 1 question about the middle layer file.
Looks like the issue creator in #18 managed to create the opposite hand's file.
But I'm a noob so would be awesome if someone can point out how to create the opposite hand's stl file for this one: https://github.com/keebio/iris-case/blob/master/rev3-only/Iris%20R3%20Middle%20Layer%20-%20Normal%20for%201.5mm%20Plate.stl

Thanks.

take, 2019-08-02:
was able to do this using autodesk netfabb 🎉
https://www.youtube.com/watch?v=mU_oB31Y_tg

Closed 2019-08-02.

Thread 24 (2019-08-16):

[REQUEST] rev. 3 right half middle layers

nstetter, 2019-08-16:
Hi,

first off: thanks for making the designs for the cases available!

When I had a look at the rev. 3 middle layers I noticed the cut-outs for the USB and TRRS jacks are not centered, so I can just 3D print the part twice and flip it around.

I would really much appreciate it, if you could make STL files for the right hand halves of the rev. 3 middle layers which have the correct mirrored  jack positions.

Thank you very much.

nstetter, 2019-08-16:
#23

I mirrored the STL part using tinkercad.

Closed 2019-08-16.

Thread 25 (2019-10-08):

Plate cover case

guestisp, 2019-10-08:
Any printable case to cover the sandwitch plate without dissoldering the PCB and chaning the plate itself ?

nooges, 2020-08-10:
See https://github.com/keebio/iris-case/blob/master/Iris%20Hi-Pro%20Top%20-%20Full%20Cover%2C%20shell.stl

Closed 2020-08-10.

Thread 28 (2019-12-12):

Which screws to use for the Hi-Pro Top Full shell?

jezdez, 2019-12-12:
For the Hi-Pro Top Full shell, which screws best to use on top of a top plate?

I think the hole is 5 mm deep, so 8 mm M2 screws?

/cc @nooges

nooges, 2020-08-10:
I think I usually use 10mm M2 screws on mine.

Closed 2020-08-10.

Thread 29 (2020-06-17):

No middle layer can be resized to 153.7mm x 132.5mm

NSCoder, 2020-06-17:
Hi Maintainers,

Thank you for your work on this project! Quick question, it seems to be that there is no middle plate for rev4 that can be resized to the appropriate dimensions specified in the readme file. I am missing something?

Thank you

lalde, 2020-06-28:
I had the same issue, I couldn’t resize it to the proper dimensions when importing the file on Ponoko or Sculpteo websites. I ended up taking the .ai file and modifying the dimensions directly in Adobe Illustrator. I then got the middle layer cut by Ponoko and it looks great. Hope this can help :)

nooges, 2020-11-19:
Ignore the README file dimensions for the mid, that was for one specific version of it.

Closed 2020-11-19.

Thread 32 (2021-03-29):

Switch plate hole size

ThreepE0, 2021-03-29:
Hello, hope all is well.  I'm noticing when I open the illustrator file for 1.5mm thick switch plate in Illustrator, the holes in the plate measure 15.45mm wide (too wide) and 13.85mm tall (not tall enough.) Verified by printing out and trying to fit switches.  I created new illustrator files and converted to svg then stl, and once printed they seem to fit much better (though to keep things simple I went with plain square holes.)

I'm wondering if I'm missing something though, because I see others are mentioning that they've had success with these files.

Any help would be greatly appreciated

nooges, 2021-03-29:
The larger width is to support Alps-compatible switches, and the 13.85mm height was to support kerf for laser cutting, although even without kerf, 13.85mm still tends to work well.

ThreepE0, 2021-03-29:
hmm.... Would you be able to measure the inside of one of the resulting holes with calipers to see what the resulting cavity measures as on the steel and/or acrylic plates?  I'm having to bump up to 14.25mm in order to just barely fit (14.3 fits loosely,) though I'm 3d printing and not cutting.

I'm only printing in an effort to get the measurements right so I can send off plates to get cut though.  I would just use the provided design files, but I'm trying to add two thumb buttons per plate.

Thanks again

Closed 2021-03-31.

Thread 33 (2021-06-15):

Iris R4 Middle Layer - Ergodox Tent Kit for 3mm Plate does not have holes that go all the way through

NekoNoor, 2021-06-15:
I just printed [this file](https://github.com/keebio/iris-case/blob/master/rev3-and-rev4/Iris%20R4%20Middle%20Layer%20-%20Ergodox%20Tent%20Kit%20for%203mm%20Plate.stl), and when i tried to assemble it i noticed that the holes in the middle layer don't go all the way through, so i can not put it together

i checked all the other middle layer files in the rev3/rev4 directory and those all have holes that go all the way through

NekoNoor, 2021-06-15:
Seems you fixed it 😄 thanks!

Closed 2021-06-15.

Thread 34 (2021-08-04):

Can't open case files

ZachariahPang, 2021-08-04:
I'm a total beginner in this. I was trying to load the `.ai` files and `.svg` files in Adobe Illustrator but all failed. `.ai` ended up with a pop-up window saying importing as a text file, and `.svg` resulted in `"This SVG is invalid"`. Is it possible this is related to some version issue?

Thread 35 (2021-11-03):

The indentations for nuts in the Ergodox Tent Kit are too large

vjraitila, 2021-11-03:
The guidance for the Ergodox tenting kit instructs using a set of M3 nuts to attach the legs. The standard diameter for DIN 934 M3 nuts is 5.5mm. However, the indents for the nuts have a diameter of 6mm in the design for "Iris R4 Middle Layer - Ergodox Tent Kit for 1.5mm Plate" .

As is it already difficult to get the legs fastened tight enough that they do not come loose, this makes it next to impossible as the nuts are allowed to spin freely in their slot. Or have I missed something relevant here?

I tried fixing this by myself, but lack the skill to do this nicely with just the mesh file being available. Perhaps even switch to a 5.5mm _square_ nut instead in order to make it less likely to spin.

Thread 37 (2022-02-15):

[Request] Upload files that made the STLs for Phoenix Edition middle layers

Zomgnomes, 2022-02-15:
As the title says, please upload the file you used to generate the STLs for the PE middle layers.

The triangulation on the STLs is kind of jacked up and it makes doing simple things like adding a chamfer to the bottom edge, and adding a lip to make a more sandwich style case that doesn't need the top bit a kind of massive pain.

nooges, 2022-02-19:
I've added the F360 files used to generate the STLs here: https://github.com/keebio/iris-case/tree/master/phoenix-edition-PE/f360

Closed 2022-02-19.

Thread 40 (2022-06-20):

PE Middle Layer Tent Kit Updates

derpmcgerp1080p, 2022-06-20:
Hello,

I noticed the design for the nut retention on the PE middle layer (Ergodox tent) has switch from a recessed M3 nut(legacy) to a square nut channel. The documentation should be updated to reflect the new requirement of a m3 square nut.

nooges, 2022-06-20:
It still uses as hex nut, but we’ve seen that fatter hex nuts are out there.

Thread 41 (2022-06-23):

PE Middle Layer USB

derpmcgerp1080p, 2022-06-23:
Hello,

The model for the PE middle layer (Ergodox/nolip) has a very small hole for the USB compared to the legacy edition. Because of this, it is incompatible with many of my USB cables as the connector is too large to fit in the whole. Requires heavy sanding to give enough clearance for cable to be inserted. Request that the main USB holes be widened to accommodate third party USB cables.7
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

nooges, 2022-07-05:
Can you measure the height and width of the housing of your USB-C cable so I can make the adjustments?

derpmcgerp1080p, 2022-07-28:
Absolutely.

Height=7.70mm
Width=13.00mm

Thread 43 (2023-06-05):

The 3mm Iris PE switch plate file is scaled incorrectly

arminAnderson, 2023-06-05:
Loaded the PE switch plate files in F360, the '1u only' file seems normal, but 'iris-PE-switch-plate-mx-3mm.dxf' is scaled up to have sides that are ~2m long. Based on the 1u file, it looks like it's around 25.4x larger than intended

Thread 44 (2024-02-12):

Ergodox tent kit with Rev-8 board breaks off transistor

ptdewey, 2024-02-12:
I printed both the ergodox 1.5mm middle layer and the tenting legs and adapters, and after installing them with M3 16mm screws, I noticed that the 6 key stopped working. Upon further investigation I found that the screw broke off the transistor for that key by pushing through it.
I followed the official iris assembly guide and the pdf in the ergodox tent legs folder.

I think adding an extra nut in the inside of the leg before the screw would reduce the amount the screw juts our of the middle layer hole, but I'm not completely certain.

This also only happened on the right board because the transistor for the keyslot on the left board is located lower on the pcb.

ptdewey, 2024-02-12:
There also appears to be some scratching of the PCBs in the other places where the screws come through also, but it seems more extreme on the right board for some reason.

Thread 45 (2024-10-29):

Stabilizers don't fit in PE Acrylic 3mm

konisteel, 2024-10-29:
Hey, so i laser cut the Iris PE Switch Plate Mx 3mm and after receiving it my stabilizers & the switches fall through the thumb area because the space it too large. The shop did not enlarge that area. How am i supposed to fit the stabilizers? I am going to handwire it so the stabs have to fit in the plate

https://github.com/user-attachments/assets/364dcd68-56ff-40d8-9d20-8b80f713b90c

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

Thanks for the help

nooges, 2024-10-29:
The cutout around the 2u key for 3mm plate is large to accommodate the stabilizer wire/housing. Otherwise, the wire and housing would hit the underside of the plate. Hence, the 3mm plate isn’t geared towards handwiring and more for use with a PCB.

konisteel, 2024-10-29:
Yea i figured that part out later after a lot of troubleshooting. Is it possible to use an adapter over there? The adapter will be 1.5mm and hold the switch & the stabs. Just a thought

nooges, 2024-10-29:
I’ll have to check my files, but I may have already designed a 3D-printable adapter to hold the switch in-place.

konisteel, 2024-10-29:
There is already a file to hold 2 1u switches but i want to use 1 2u
If you have the files, It would be a great help 🙏.
Thanks

konisteel, 2024-10-29:
Did you fine the stl file?

nooges, 2024-10-29:
I checked my Fusion 360 projects, and it doesn't look like I've designed a
2u adapter yet, but I can give it a go later this week.

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

konisteel, 2024-10-29:
That Would help me out a bunch, and others who will use it :D
Can't wait for the files and the new update

nooges, 2024-10-31:
Yeah, I'm working something up right now and will do some test printing

konisteel, 2024-11-01:
Great!

konisteel, 2024-11-03:
Hey when can we expect the stl file :p

konisteel, 2024-11-04:
[keyboard adapter.zip](https://github.com/user-attachments/files/17617488/keyboard.adapter.zip)

nooges, 2024-11-06:
Turns out I did have something designed previously, see how this works out for you.
[Iris PE 2u Adapter for 3mm Plate.stl.zip](https://github.com/user-attachments/files/17649087/Iris.PE.2u.Adapter.for.3mm.Plate.stl.zip)

nooges, 2024-11-06:
If recutting the plate is an option, you could go with the older-style cutout in iris-PE-switch-plate-mx-alps.dxf

konisteel, 2024-11-06:
Hey how does the file work? I'm confused
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

nooges, 2024-11-06:
It’s not particularly great with handwiring though, so I don’t really have a good solution for using the plate as-isOn Nov 6, 2024, at 10:35 AM, Konisteel ***@***.***> wrote:
Hey how does the file work? I'm confused
image.png (view on web)

—Reply to this email directly, view it on GitHub, or unsubscribe.You are receiving this because you commented.Message ID: ***@***.***>

konisteel, 2024-11-06:
Alright i'll receive the 3d printed adapter that i uploaded and check if everything works great. I'll keep you updated but so far if you use the top plate than a little sanding is necessary or else it'll fit on the plate no problem with normal mx switches and cherry stabs

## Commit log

2018-02-22 Add interior screw plate designs
2018-03-29 Update interior screw bottom plate design to remove double lines
2018-06-03 added cad files
    [bottom_left.dxf, bottom_right.dxf, top_left.dxf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]
2018-06-15 Add mid layer for internal screw plates
    [Iris Internal Mid.stl]
2018-10-03 STL files for 3d printing iris mid layers
    [Iris Middle Layer.stl, Iris Middle Tented.stl]
2018-10-11 Fix scaling on iris mid layer STL files
    [Iris Middle Layer.stl, Iris Middle Tented.stl]
2018-10-11 12mm height, not 12.2mm on tented mid
    [Iris Middle Tented.stl]
2018-11-16 Added 3D print case and documentation
    [iris_case.scad]
2018-11-16 Added case picture to readme
2018-12-03 Add STL files for printed mids
    [Iris Mid - Ergodox Tent Kit.stl, Iris Mid - Single Piece.stl]
2018-12-03 Rename files
    [Iris Middle Layer - Ergodox Tent Kit.stl, Iris Middle Layer - Single Piece.stl, Iris Middle Layer - Two Piece.stl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]
2018-12-14 Add thin shell version of mids for faster printing
    [Iris Thin Shell Tenting.stl, Iris Thin Shell.stl]
2019-05-05 Added Elite-C support
    [iris_case.scad]
2019-05-05 Updated readme to clarify PCBc compatibility
2019-05-14 Add rev3 mods to design file, add choc plates
2019-06-10 Reorganize files a bit, add Rev 3 mid files
    [Iris Hi-Pro Top - Thin Rim.stl, Iris Middle Layer - Ergodox Tent Kit.stl, Iris Middle Layer - Single Piece.stl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]
2019-06-21 Rename Iris R3 pieces, add note to readme
    [Iris R3 Middle Layer - 1.5mm plate - Ergodox Tent Kit.stl, Iris R3 Middle Layer - 1.5mm plate - Single Piece.stl]
2019-06-21 More renaming, add R3 mid layers for 3mm plates
    [Iris R3 Middle Layer - Ergodox Tent Kit for 1.5mm Plate.stl, Iris R3 Middle Layer - Ergodox Tent Kit for 3mm Plate.stl, Iris R3 Middle Layer - Normal for 1.5mm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]
2019-07-08 Add R3 bottom plate
2019-07-22 Move 3d openscad files to community folder
    [iris_case.scad]
2019-07-23 Rename various files
    [Iris Middle Layer for Interior Screw Plates.stl, Iris R3 Middle Layer - Tented for 1.5mm Plate.stl, iris-rev2-bottom_left.dxf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]
2019-07-23 Update README file
    [Iris Middle Layer for Interior Screw Plates.stl]
2019-09-08 Add switch plate for 3mm thick material
    [iris-rev3-bottom-plate.dxf, iris-switch-plate-3mm-thick.dxf]
2020-03-27 Rename directory
    [Iris R3 Middle Layer - 2 Piece.stl, Iris R3 Middle Layer - Ergodox Tent Kit for 1.5mm Plate.stl, Iris R3 Middle Layer - Ergodox Tent Kit for 3mm Plate.stl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]
2020-10-27 Add files for Iris Rev. 4 mid layers
    [iris-rev4-left-middle-layer.stl, iris-rev4-right-middle-layer.stl]
2020-10-28 Add Iris R4 mid layer with Ergodox leg support
    [Iris R4 Middle Layer - Ergodox Tent Kit for 1.5mm Plate.stl]
2021-06-09 Add new top shell files and rev 3/4 readme
    [Iris R4 Middle Layer - Ergodox Tent Kit for 3mm Plate.stl, Iris Top Shell Rev. 4 - With Encoder.stl, Iris Top Shell Rev. 4.stl]
2021-06-15 Add missing standoff holes on bottom of file
    [Iris R4 Middle Layer - Ergodox Tent Kit for 3mm Plate.stl]
2021-08-18 Add Phoenix Edition plates
    [iris-PE-bottom-plate.dxf, iris-PE-mid-normal.dxf, iris-PE-mid-tented.dxf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]
2021-09-30 Add more PE parts
    [iris-PE-mid-layer-acrylic.dxf, iris-PE-switch-plate-choc.dxf, iris-PE-switch-plate-mx-alps-3mm.dxf]
2021-11-19 Add mid layer Iris PE files for printing
    [Iris PE Middle Layer - Ergodox Tent Kit No Lip for 1.5mm Plate.stl, Iris PE Middle Layer - Ergodox Tent Kit for 1.5mm Plate.stl, Iris PE Middle Layer - Ergodox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]
2021-11-19 Add STEP files for Rev. 5 and 6 PCBs
2021-11-19 Add top shells for PE and update README
    [Iris PE Top Shell for 1.5mm plate.stl, Iris PE Top Shell for 3mm plate.stl]
2021-11-19 Update readme, move files around
    [Iris Hi-Pro Top - Thin Rim.stl, Iris Middle Tented - Two Piece.stl, Iris R2 Middle Layer - Ergodox Tent Kit.stl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]
2021-11-29 Add ridges inside of Ergodox holes to allow legs to lock into position when screwed in
    [Iris PE Middle Layer - Ergodox Tent Kit No Lip for 1.5mm Plate.stl, Iris PE Middle Layer - Ergodox Tent Kit for 1.5mm Plate.stl, Iris PE Middle Layer - Ergodox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]
2021-12-23 Move non-enclosed Iris LE files into directory
    [Iris Hi-Pro Top - Thin Rim.stl, Iris R3 Middle Layer - 2 Piece.stl, Iris R3 Middle Layer - Ergodox Tent Kit for 1.5mm Plate.stl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]
2022-01-12 Add alignment tool for SKUF feet
    [Iris Bottom Plate SKUF Alignment Guide.stl]
2022-02-19 Add F360 source files for generating STLs
    [Iris LE Mid v42.f3z, Iris LE-PE Top Shell v14.f3d]
2022-02-23 Add ErgoDox-style tenting legs, and glue-in adapter, to use a toothed hirth-joint style connection.
    [ErgoDox-style Toothed Tenting Leg Adapter.stl, ErgoDox-style Toothed Tenting Leg.stl]
2022-03-10 Fix larger screw hole sizes for two of the holes in top shell, change fillet of outer edges to chamfer
    [Iris LE-PE Top Shell v14.f3d, Iris LE-PE Top Shell v15.f3d, Iris PE Top Shell for 1.5mm plate.stl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]
2022-09-08 Add 1u adapter
    [Iris PE 1u Adapter for 3mm Plates.stl]
2023-02-10 Add more plate designs and Iris LE mid layers
    [Iris LE Middle Layer - Ergodox Tent Kit for 1.5mm Plate.stl, Iris LE Middle Layer - Normal for 1.5mm Plate.stl, iris-PE-switch-plate-mx-1u-only.dxf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]
2025-02-12 Add link to Iris AE case
